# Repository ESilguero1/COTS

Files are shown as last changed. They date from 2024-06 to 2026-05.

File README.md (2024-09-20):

Celestial Object Tracking System is our take on GOTO teslescope systems with extra features
telescope







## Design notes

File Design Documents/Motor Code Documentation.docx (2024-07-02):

# MOTOR CODE DOCUMENTATION

Summer 2018

Jessica Chapman

Date | Editor | Reason
2018-08-29 | Jessica Chapman | Created Document

| Table of Contents
How it works | 1.1 Motor Setup | 1.1.1 Comm and Datagrams
| | 1.1.2 How to Use It
| | 1.1.3 Improvement
| | 1.1.4 Command Guide
Programming | 2.1 Motor Code | 2.1.1 How it Works
| | 2.1.2 Editing Code
Circuits | 3.1 Motor Circuit | 3.1.1 List of Supplies
| | 3.1.2 Pin Connection Guide
Appendix | 4.1 Additional Information | 4.1.1 List of Links

# 1.1 Motor Setup

## 1.1.1 Communication and Datagrams

The motor setup uses a TMC5130 board with a stepper motor and Arduino Mega. The TMC communicates with the Arduino using an SPI interface using a 40-bit datagram structure. The datagram is split into two parts: the address (8 bits) and the information to send (32 bits), with the MSB transmitting first, the MSB of the address (bit 39) will define whether it is going for read (0) or write (1) access. 0x80 can be added to the address to achieve write access instead of read access.

40 Bit SPI Datagram Structure Writing

7-Bit Address

38-32

32-Bit Data

31-0

40 Bit SPI Datagram Structure Reading

Previous 32-Bit Data

31-0

1

39

7-Bit SPI Status

38-32

0

39

The SPI has four main signal types going from the master (Arduino) to control the slave (TMC5130). To hook up multiple motor controllers, they can be daisy chained together and enabled for communication using the CSN Pin. Note that the clocks must be set properly so that the communication speed is within range for the master and the slaves.

SCK | Bus Clock Input
SDI | Serial Data Input
SDO | Serial Data Output
CSN | Chip Select Input (Active Low)

## 1.1.2 How to Use the Program to Control a Motor

The loop in the Motor Communication INO file should be as fast as possible so as not to clog up the serial monitor, which can cause NULL problems in a python file attempting to communicate to the Arduino. Currently the loop takes about 30-200 µsec to complete.

Process | Time [µsecond]
Feed in Serial Data | 20
User Control Via Joystick | 100
Seeking a Limit Switch | 12
Is moving to a Position | 50

To use it, open up the Arduino IDE and then open the serial monitor. Change the Baud Rate to 57600 and the motor initialization information should appear on the screen. You should hear a small humming sound coming from the motor. Type in the command using the ‘Input’ under ‘List of Commands’ below, you can also find them in the Enum.h file (type in the number not the name). Make sure every command ends in a “;” and there are no additional spaces. If you get an e,unknown command; it likely means you have not formatted it correctly. If the motor does not respond and you do not hear the humming, make sure you are supplying 24V to the motor.

1. Open up Arduino IDE and Serial Monitor
2. Set Baud Rate to 57600
3. Send a command in the format [number],[*args]; with no spaces, and a comma between each argument, with a semicolon at the end
4. An S,1; response means the command was properly received and processed and S,0; response means that the command was not properly received (check the amount of arguments or if you already have a process going on such as ‘Home’)

## 1.1.3 Suggestions for Improvement

- Better input command structure. There are safety features built in to send a failure status if the command is not correctly formatted or is missing an argument.
- Possibly building a GUI with python to call the different controls and such
- Hardware switch that overrides the current commands and goes straight to the Joystick control
- Checking motor is properly connected when sending commands (ie: code pings motor to see if it’s alive and then returns some sort of status bit or something)
- Output the position of the motor when using the joystick to find how far something is (maybe building an absolute and a relative position function)
- An easy set position on the joystick, click a button or something and the program sets the exact position of the motor as the home position
- An actual PCB / Enclosure, not just a messy breadboard. A box where you can just stick in an arduino cord to load code and the motor connections would be super nice

## 1.1.4 Command Guide

The setup uses a TMC5130 Board, Arduino Mega, Stepper Motor, and a Joystick. The code is based on a stepper motor with 256 microstep resolution. The motor is run off of 24V and the arduino can be controlled from the Arduino IDE Serial Monitor or a python script.

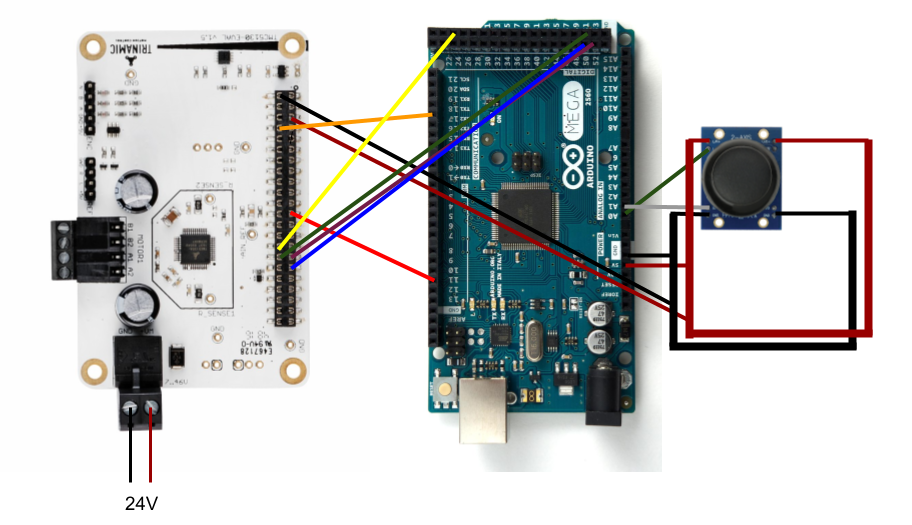
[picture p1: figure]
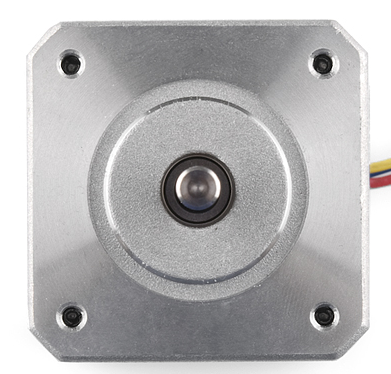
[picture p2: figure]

The setup also has the possibility for two limit switches to be added just above the motor connections, the switch configurations can be set using the commands below.

Default Settings of Motor Directions and Limit Switches
Forward Direction | Backward Direction | Right Limit Switch | Left Limit Switch
Clockwise | Counter-Clockwise | Forward Hit | Backward Hit

Note that the absolute position is described as the position relative to “Home” or point 0.

List of Commands
Command | Input | Output

Returns the 25-bit status from multiple registers. See table below for detailed description.
onRequestMotorStatus | 10; | m,[time],[bit0],[bit1],...,[bit24];

Returns the 10-bit status from the Drive Status Register. It gives a means to measure mechanical load on the motor, a value of 0 signals the highest load (stall).
onRequestStallStatus | 11; | g,[time],[bit0],[bit1],...,[bit9];

Changes the position specified to the current position of the motor (changes the step reference of the motor). The motor does not move to the specified position, but instead it becomes its position.
onRequestSetPosNoMove | 12; | d,[time],[oldPos],[newPos];

Gets the ADC bits from the Arduino (Mega = 10 bit ADC).
onGetADCBits | 20; | A,[ADC];

Gets the reference voltage of the Arduino (Mega = 5.0V)
onGetADCRefVolt | 21; | V,[5/3.3/2.56];

Gets the absolute position of the motor in microsteps.
onGetXactual | 22; | x,[time],[Xactual];

Gets the current velocity of the motor.
onGetVelocity | 23; | v,[time],[Velocity];

Gets the current maximum acceleration that the motor can achieve to reach maximum velocity.
onGetAcceleration) | 24; | a,[time],[Acceleration];

Gets the current maximum decceleration that the motor can achieve to reach 0 velocity.
onGetDeceleration | 25; | d,[time],[Decceleration];

Gets the IHOLD_IRUN (driver current control) power going to the motor
onGetPower | 26; | P,[time],[Power];

Moves the motor forward at the speed specified continuously until the motor is stopped or a limit switch is pressed. Note that forward defaults to clockwise.
onConstantForward | 30,[speed]; | S,[1/0];

Moves the motor backward at the speed specified continuously until the motor is stopped or a limit switch is pressed. Note that backward defaults to counterclockwise.
onConstantBackward | 31,[speed]; | S,[1/0];

Moves to the absolute position specified.
onMovePosition | 32,[absolute position]; | S,[1/0];

Moves a relative number of steps forward at the speed specified.
onMoveForward | 33,[number of steps],[speed]; | S,[1/0];

Moves a relative number of steps backward at the speed specified.
onMoveBackward | 34,[number of steps],[speed]; | S,[1/0];

Sets the maximum velocity achievable by the motor. For reference, the standard speed (ie: the speed of the motor used for onMovePosition) of the motor has been set to 100 000 µ/sec. 200 000 µ/sec is very fast, definitely do not exceed 300 000 µ/sec.
onVelocity | 35,[velocity]; | S,[1/0];

Sets the maximum acceleration achievable by the motor. The default is set to 50 000 µ/sec².
onAcceleration | 36,[acceleration]; | S,[1/0];

Sets the maximum decceleration achievable by the motor. The default is set to 50 000 µ/sec².
onDecceleration | 37,[decceleration]; | S,[1/0];

Sets the hold and run power going to the motor.
onPower | 38,[holdpower],[runpower]; | S,[1/0];

Sets the clockwise direction of the motor and the forward switch. See table below for detailed description.
onDirection | 39,[mode 1/2/3/4]; | S,[1/0];

Enable joystick control. A constant moving command will override the JS enable and disable the JS.
onJSEnable | 40; | S,[1/0];

Disable joystick control.
onJSDisable | 41; | S,[1/0];

Stop the motor. Can be used while any other command is currently going.
onMotorStop | 42; | S,[1/0];

Home the motor. The motor will run in the forward direction until it hits the forward limit switch and that will become the 0-point.
onMotorHome | 43; | S,[1/0];

Seek a limit switch in the direction specified.
onSeek | 44,[direction to go]; | S,[1/0];

Change the resolution of the motor, the possible settings are: 256, 128, 64, 32, 16, 8, 4, 2, 1. The motor defaults to 256.
onResolution | 45,[resolution]; | S,[1/0];

Set whether the switches are active high or active low. 0 = active high, 1 = active low.
onActiveSettings | 46, [fwActive],[bwActive]; | S,[1/0];

Request Motor Status
Bit Number | Status Bit
0 | status_sg2
1 | status_sg2_event
2 | status_standstill
3 | status_velocity_reached
4 | status_position_reached
5 | status_position_reached_event
6 | status_stop_l
7 | status_stop_r
8 | status_stop_l_event
9 | status_stop_r_event
10 | status_latch_l
11 | status_latch_r
12 | status_openLoad_A
13 | status_openLoad_B
14 | status_shortToGround_A
15 | status_shortToGround_B
16 | status_overtemperatureWarning
17 | status_overtemperatureShutdown
18 | status_isReverse
19 | status_resetDetected
20 | status_driverError
21 | status_underVoltage
22 | getIsForward
23 | getIsPositionMode
24 | getIsHomed

Setting Motor and Switch Directions
Direction Mode | Forward Switch | Backward Switch | Forward Direction | Backward Direction
1 | Right | Left | CW | CCW
2 | Right | Left | CCW | CW
3 | Left | Right | CW | CCW
4 | Left | Right | CCW | CW

# 2.1 Motor Code

## 2.1.1 How It Works

The code has a 3-level hierarchy, starting with the INO file at the top and hardware control files at the bottom. The Combined Control file controls the interactions between the joystick and the motor. Additional hardware classes should be incorporated into the Combined Control file. The code is currently only designed to control one motor, but motors could be daisy-chained together with some small edits to the code to control the slave enable-disable for multiple motors.

Combined Control

Motor INO

Joystick Control

Motor Control

### Motor Control File

At the lowest level, the motor is controlled by registers which you send values to through an SPI interface between the motor controller and the Arduino. The program uses datagram structures which are split into three parts: the read or write access (rw) which is bit 39, the address which is bits 38-32, and the data which is bits 31-0 (the datagrams are MSB first).

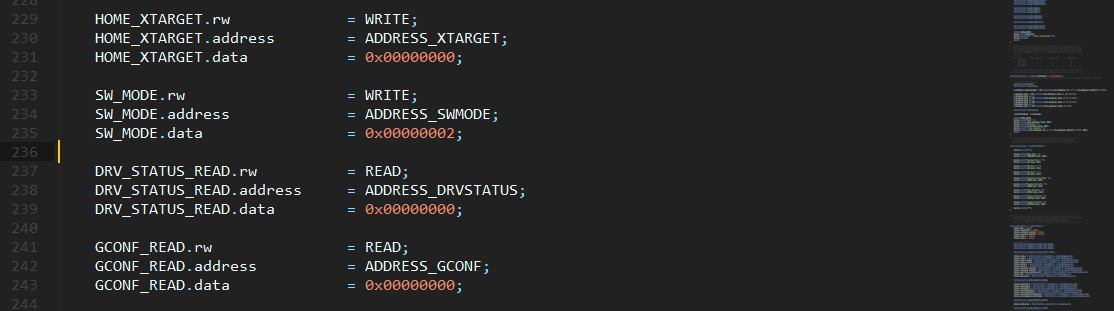
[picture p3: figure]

When reading from the motor controller, when you send a read command, the command after will be the one holding the information from the query, this can be seen in the MotorControl :: readStatus() function.

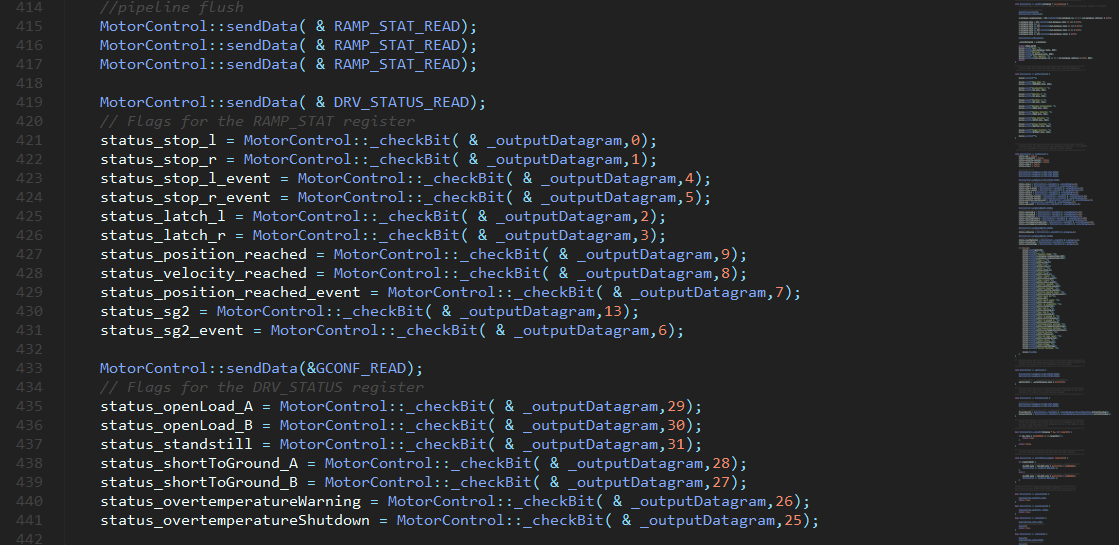
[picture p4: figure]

Note that the CS Pin for the motor controller that the command is meant for should only be enabled while sending the command and should be disabled after.

In addition, anything that requires movement, direction, or the limit switches should be done using the directionControl Struct. The forward/backward directions and limit switches are software controlled in Motor Control (instead of changing the registers, which causes many problems when ccw -/-> left switch and cw -/-> right switch).

### Joystick Control File

The joystick can be used to control many different aspects of the motor, such as speed, power, acceleration, direction. Currently it is set to control the speed and direction of motors. The Joystick control does not follow the settings for the forward and backward switches and motor directions.

Current Joystick Control Settings
Y-Direction | X-Direction
Speed of Motor | Direction of Motor

To save serial monitor time (sending bits to the register is a slow process), the Combined Control limits the values that will be updated such that the speed will only be updated if it is outside the range of +/-10% of the previous set reading.

## 2.1.2 Editing Code

To edit the code for more low level commands you need to use the registers provided in the definitions file and ensure the datagram has been set up (as that is how commands are sent to the motor). See chapter 6 (https://www.trinamic.com/fileadmin/assets/Products/ICs_Documents/TMC5130_datasheet_Rev1.15.pdf) for how to change the registers for what you need.

When you need to send information to the motor you should follow the format:

XTARGET.data = xtarget;

MotorControl :: sendData(&XTARGET);

To add new Serial Control Commands:

1. In the Enum.h file, add a definition ( __DEFINITION__ ) to the appropriate spot and assign a number
2. In MotorCommunication.ino under void attachCommandCallbacks() add your command using the format:

cmdMessenger.attach( __DEFINITION__, __FUNCTION__ );

3. Still in MotorCommunication.ino, add your function ( __FUNCTION__ )

To control the movement of the motor, I suggest calling one of the four already made functions (constForward, forward, constReverse, reverse) and using them in CombinedControl instead of making your own function in MotorControl; this is to keep from developing bugs in the software direction control. If you choose to make your own in MotorControl function, keep in mind the different ramp modes to use:

Ramp Mode | Position Mode | Direction
RAMP_MODE0 | True | --
RAMP_MODE1 | False | Forward
RAMP_MODE2 | False | Backward
RAMP_MODE3 | -- | --

# 3.1 Motor Circuit

## 3.1.1 List of Supplies

Supplies | Documentation | Additional Resources
TMC5130 Eval (https://www.trinamic.com/support/eval-kits/details/tmc5130-ev/) | User Manual and Cmd Guide (https://www.trinamic.com/fileadmin/assets/Products/Eval_Documents/TMC5130_Eval_manual.pdf) | Example Setup (http://blog.trinamic.com/2017/04/05/how-to-use-tmc5130-eval-with-your-arduino-mega/)
Arduino Mega 2560 (https://store.arduino.cc/usa/arduino-mega-2560-rev3) | Schematic (https://www.arduino.cc/en/uploads/Main/arduino-mega2560_R3-sch.pdf) | Pin Mapping (https://www.arduino.cc/en/Hacking/PinMapping2560)
2-Axis Joystick (https://www.parallax.com/product/27800) | Schematic (https://www.parallax.com/sites/default/files/downloads/27800-2-Axis-Joystick-Schematic-RevB.pdf) | Arduino Code (https://www.arduino.cc/en/Tutorial/JoyStick)

Additionally, the setup requires a stepper motor (https://catalog.orientalmotor.com/item/cvd-2-phase-bipolar-stepper-motor-drivers/legacy-pkp-series-2-phase-bipolar-stepper-motors/pkp244d23a), a 24V Power Cord + jack, 2 limit switches, a breadboard or PCB, and some jumper cables. Toggle switches are also useful for enabling/disabling the joystick and for turning on/off the power to the motor.

## 3.1.2 Pin Connection Guide

The pins going from the Arduino to the TMC5130 can be connected with or without the pin connector piece and Evaluation Platform (see page 5 (https://www.trinamic.com/fileadmin/assets/Products/Eval_Documents/TMC5130_Eval_manual.pdf)), the diagrams below do not use the pin connector.

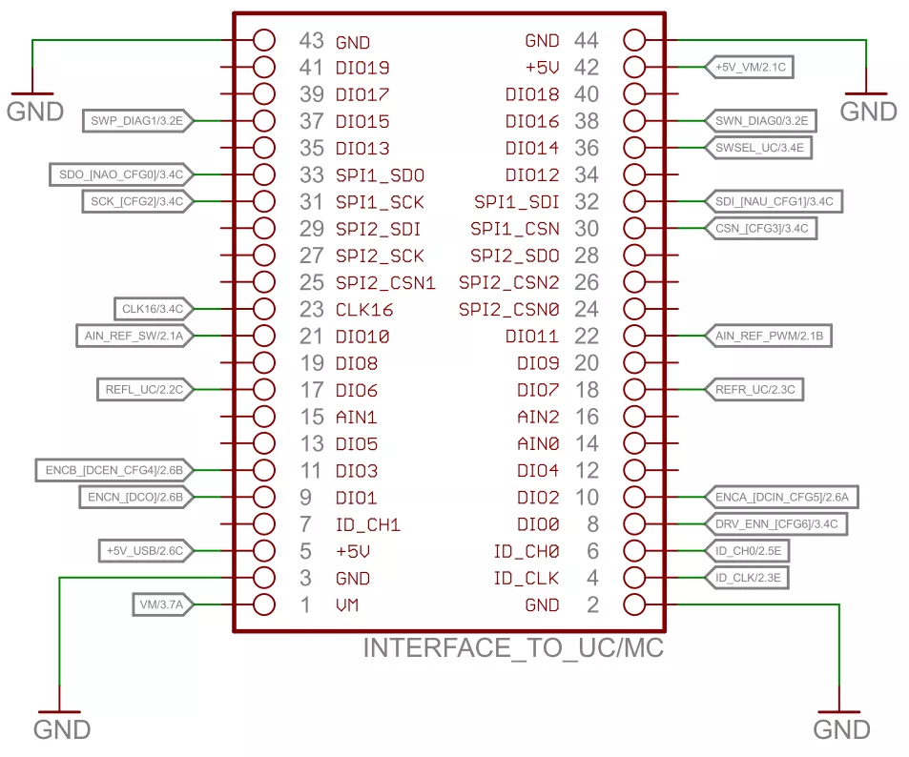
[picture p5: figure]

Arduino Pin | Type | TMC5130 Pin | Type | Colour
--- | GND | 2 | GND | Black
--- | 5V | 5 | +5V | Red
11 | DIO | 23 | CLK6 | Red
17 | DIO | 8 | DIO0 | Orange
25 | CS | 30 | SPI1_CSN | Yellow
50 | MISO | 33 | SPI1_SDO | Blue
51 | MOSI | 32 | SPI1_SDI | Purple
52 | SCK | 31 | SPI1_SCK | Green

Arduino Pin | Joystick | Colour
GND | Both GND Pins | Black
5V | L/R+ and U/D+ | Red
A0 | L/R | Green
A1 | U/D | Grey

# 4.1 Appendix

## 4.1.1 Relevant Links

GitHub | https://github.com/ProjektEskie/PNI-Sensors/tree/master/Motor%20Code
TMC5130 DataSheet | https://www.trinamic.com/fileadmin/assets/Products/Eval_Documents/TMC5130_Eval_manual.pdf
TMC5130 Cmd Guide | https://www.trinamic.com/fileadmin/assets/Products/ICs_Documents/TMC5130_datasheet_Rev1.15.pdf

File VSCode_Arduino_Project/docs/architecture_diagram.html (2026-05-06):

# COTS — Software Architecture

Arduino Due · TMC5130 × 3 · HWT906 IMU · BLE UART (Seeed nRF52) · Horizonless Embedded Solutions LLC

External Interfaces

Python Host

CmdMessenger protocol · USB Serial (COM3, 115200)

BLE Mobile App

Seeed nRF52 BLE UART · CRC32-framed packets

Application Layer

BLE_Bridge_App

Init · Service_BLE_UART()
println() → both channels

System_Control_App

ServiceSystemResponseApp() · 30+ CmdMessenger callbacks
Motor flags · seek/position state machine

HWT906_App

Init · CheckIMUDataCollection()
6-axis avg · UART1 interrupt

LED_App

Init state blink encoding
Service_LED() · Toggle_LED()

Scheduler · Main.cpp

loop()

SystemControlApp.Service()
BLE_App.Service_BLE_UART()
asyncTask.loop()

AsyncTask — Periodic Tasks

Mtr3PowerDisableCheck · 1000 ms ServiceIMUapp · 233 ms ServiceLEDapp · 250 ms ServiceJSswitch · 500 ms

setup()

Motor disable → LED → HWT906
→ SystemControl → BLE
→ Motor status checks

Middleware / Control Layer

CombinedControl

Wraps MotorControl[0..2] + Joystick
goPos · seek · constForward/Reverse · standstill · status()
Joystick enable/disable · range checks per motor

CmdMessenger

Serial command parser
feedinSerialData()
attach() callbacks

BLE Bridge Lib

build_frame_from_cstr()
parse_frame()
CRC32 (IEEE 802.3)

Driver Layer

MotorControl [0]

CS: pin 10 · ENA: pin 5
readStatus() · sendData()
RAMP_STAT.vzero · VACTUAL

MotorControl [1]

CS: pin 11 · ENA: pin 6
readStatus() · sendData()
RAMP_STAT.vzero · VACTUAL

MotorControl [2]

CS: pin 2 · ENA: pin 3
Low-vel vertical axis
Auto power-disable

Joystick

A0 (Y) · A1 (X)
xAxisControl() · yAxisControl()
Threshold + range scaling

Hardware Abstraction (Arduino Framework)

SPI (MODE3 · MSBFIRST · DIV8)

40-bit pipelined datagrams · CS per motor · 1-transaction read delay

UART1 (Serial1)

HWT906 IMU
pins 18/19

UART3 (Serial3)

BLE UART
pins 16/17

ADC · GPIO

A0/A1 joystick
pin 12 LED · pin 13 JS-SW

Hardware

TMC5130 #0

Stepper Motor 0
Azimuth / Yaw axis
±180° range-limited

TMC5130 #1

Stepper Motor 1
Elevation / Pitch axis
±90° range-limited

TMC5130 #2

Stepper Motor 2
Vertical / Lift axis
On-demand power

HWT906 IMU

6-axis AHRS
Accel · Gyro · Mag
Heading + attitude

BLE Module

Seeed nRF52
BLE UART peripheral

Arduino Due

SAM3X8E
ARM Cortex-M3 · 84 MHz

External Interface

Application

Scheduler / Main

Middleware

Driver

HAL

Hardware

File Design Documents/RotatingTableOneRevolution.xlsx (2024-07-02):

Microsteps (Controller Setting) | Motor (1.8) 360/1.8 | 1 motor revolution (uSteps*1.8) | Transmission mode: worm gear (reduction ratio 1/180) | 1 Rotating Table revolution | Steps to move 1 degree
256 | 200 | 51200 | 180 | 9216000 | 25600

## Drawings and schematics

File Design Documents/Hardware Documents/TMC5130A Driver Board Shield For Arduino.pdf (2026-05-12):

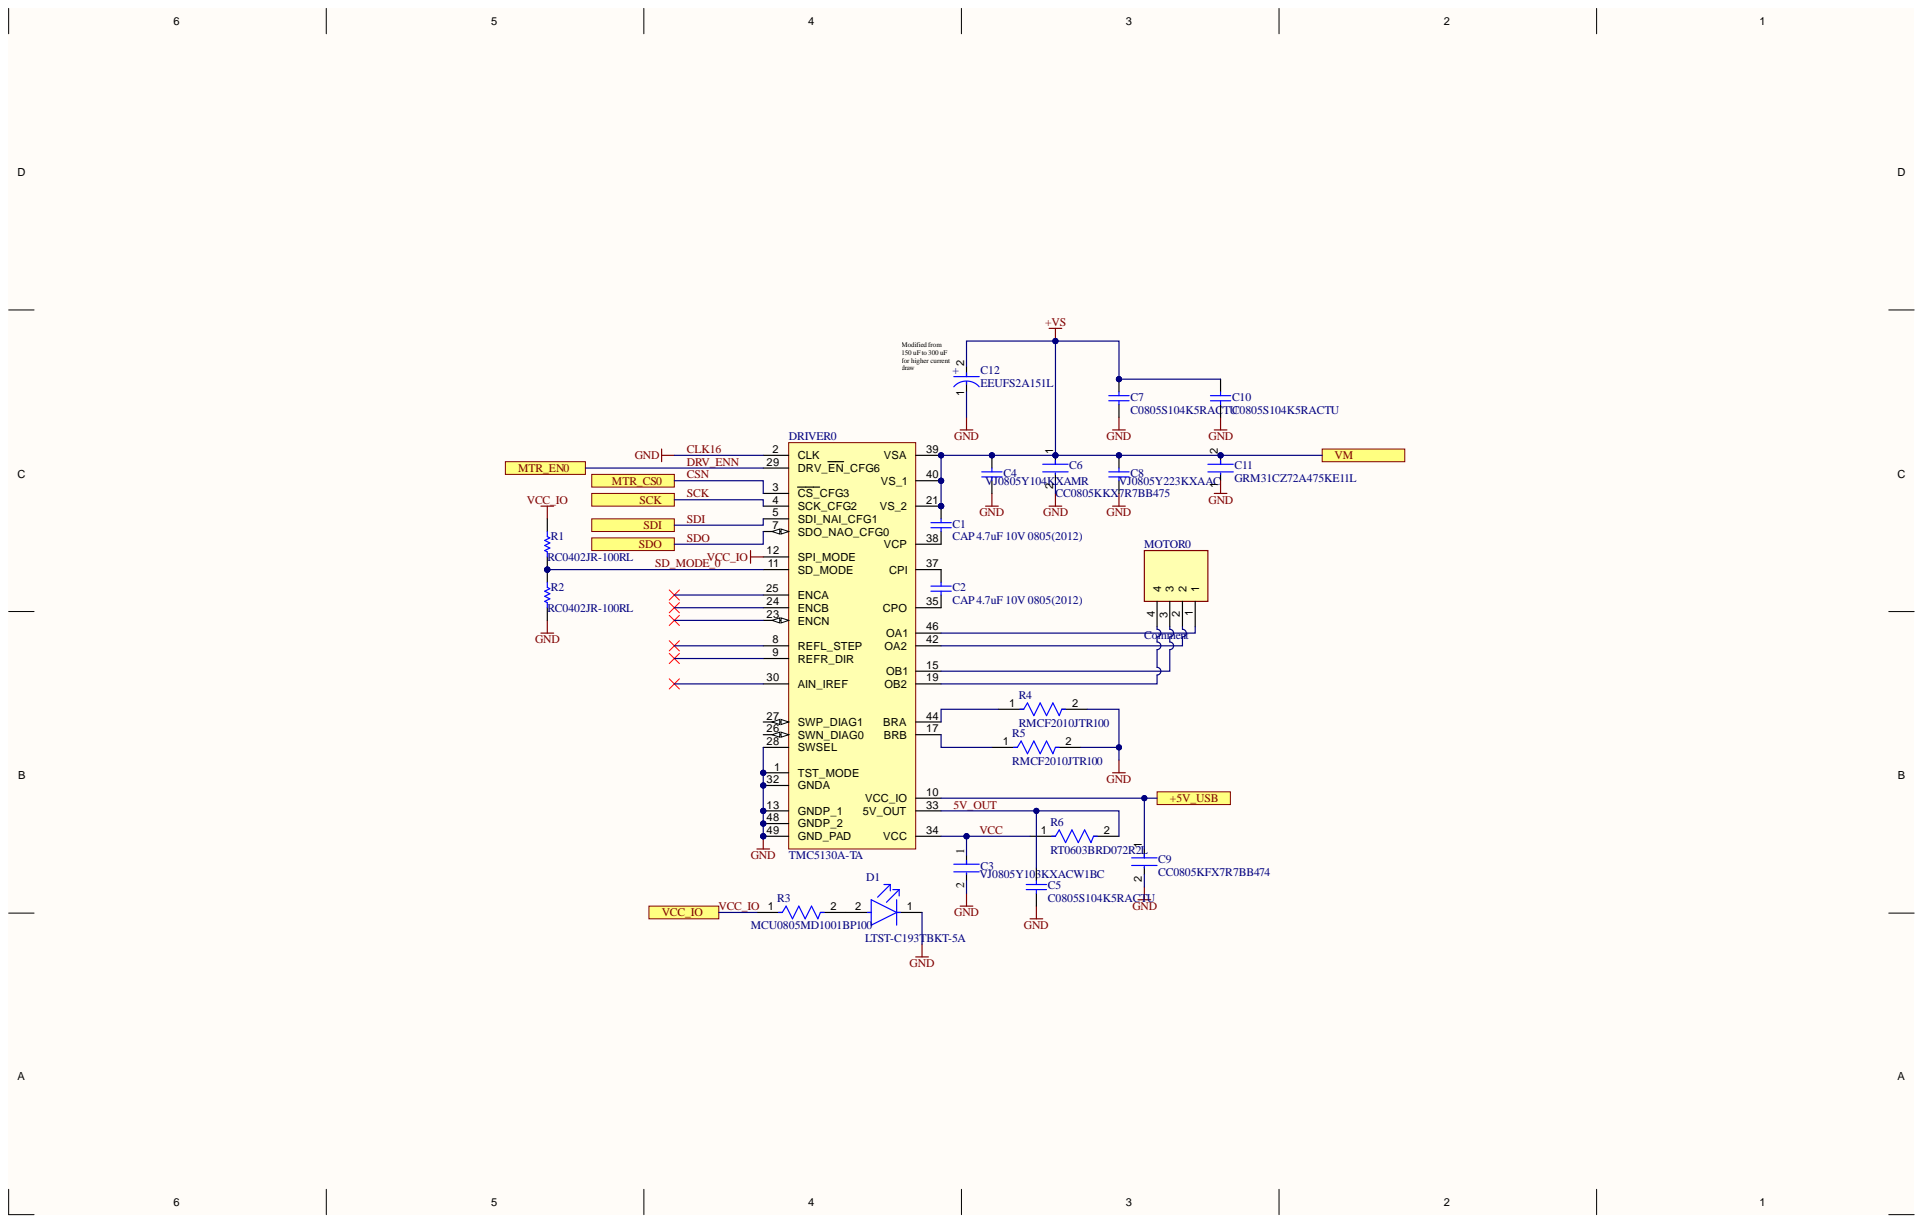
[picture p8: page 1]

SCK | SCK | SCK_CFG2 4

SDI | | SDO_NAO_CFG0 7
SDO | SDO | | SD_MODE 11 SPI_MODE 12

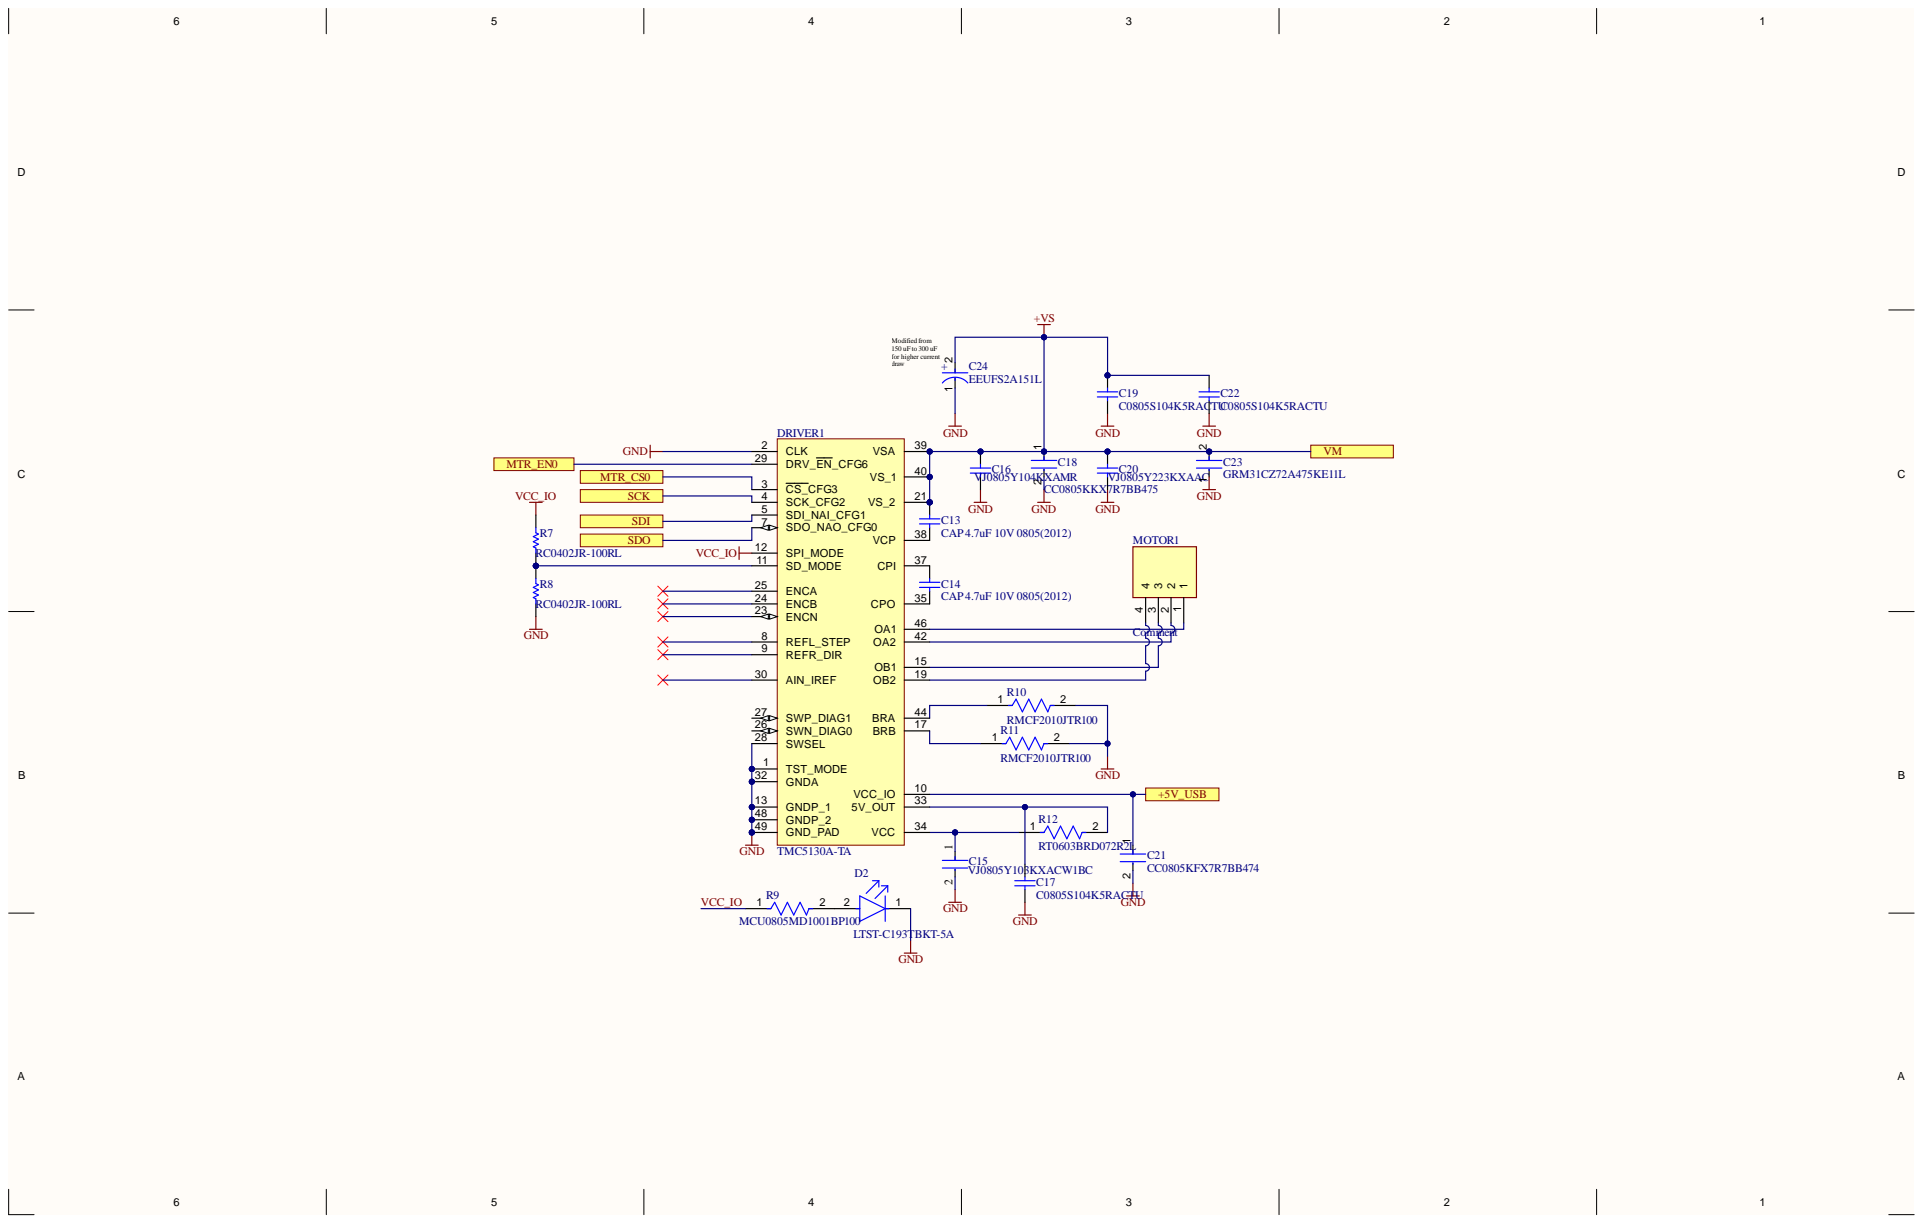
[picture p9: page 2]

MTR_EN0 | CS_CFG3 3

SDI | SDO_NAO_CFG0 7

SD_MODE 11 SPI_MODE 12

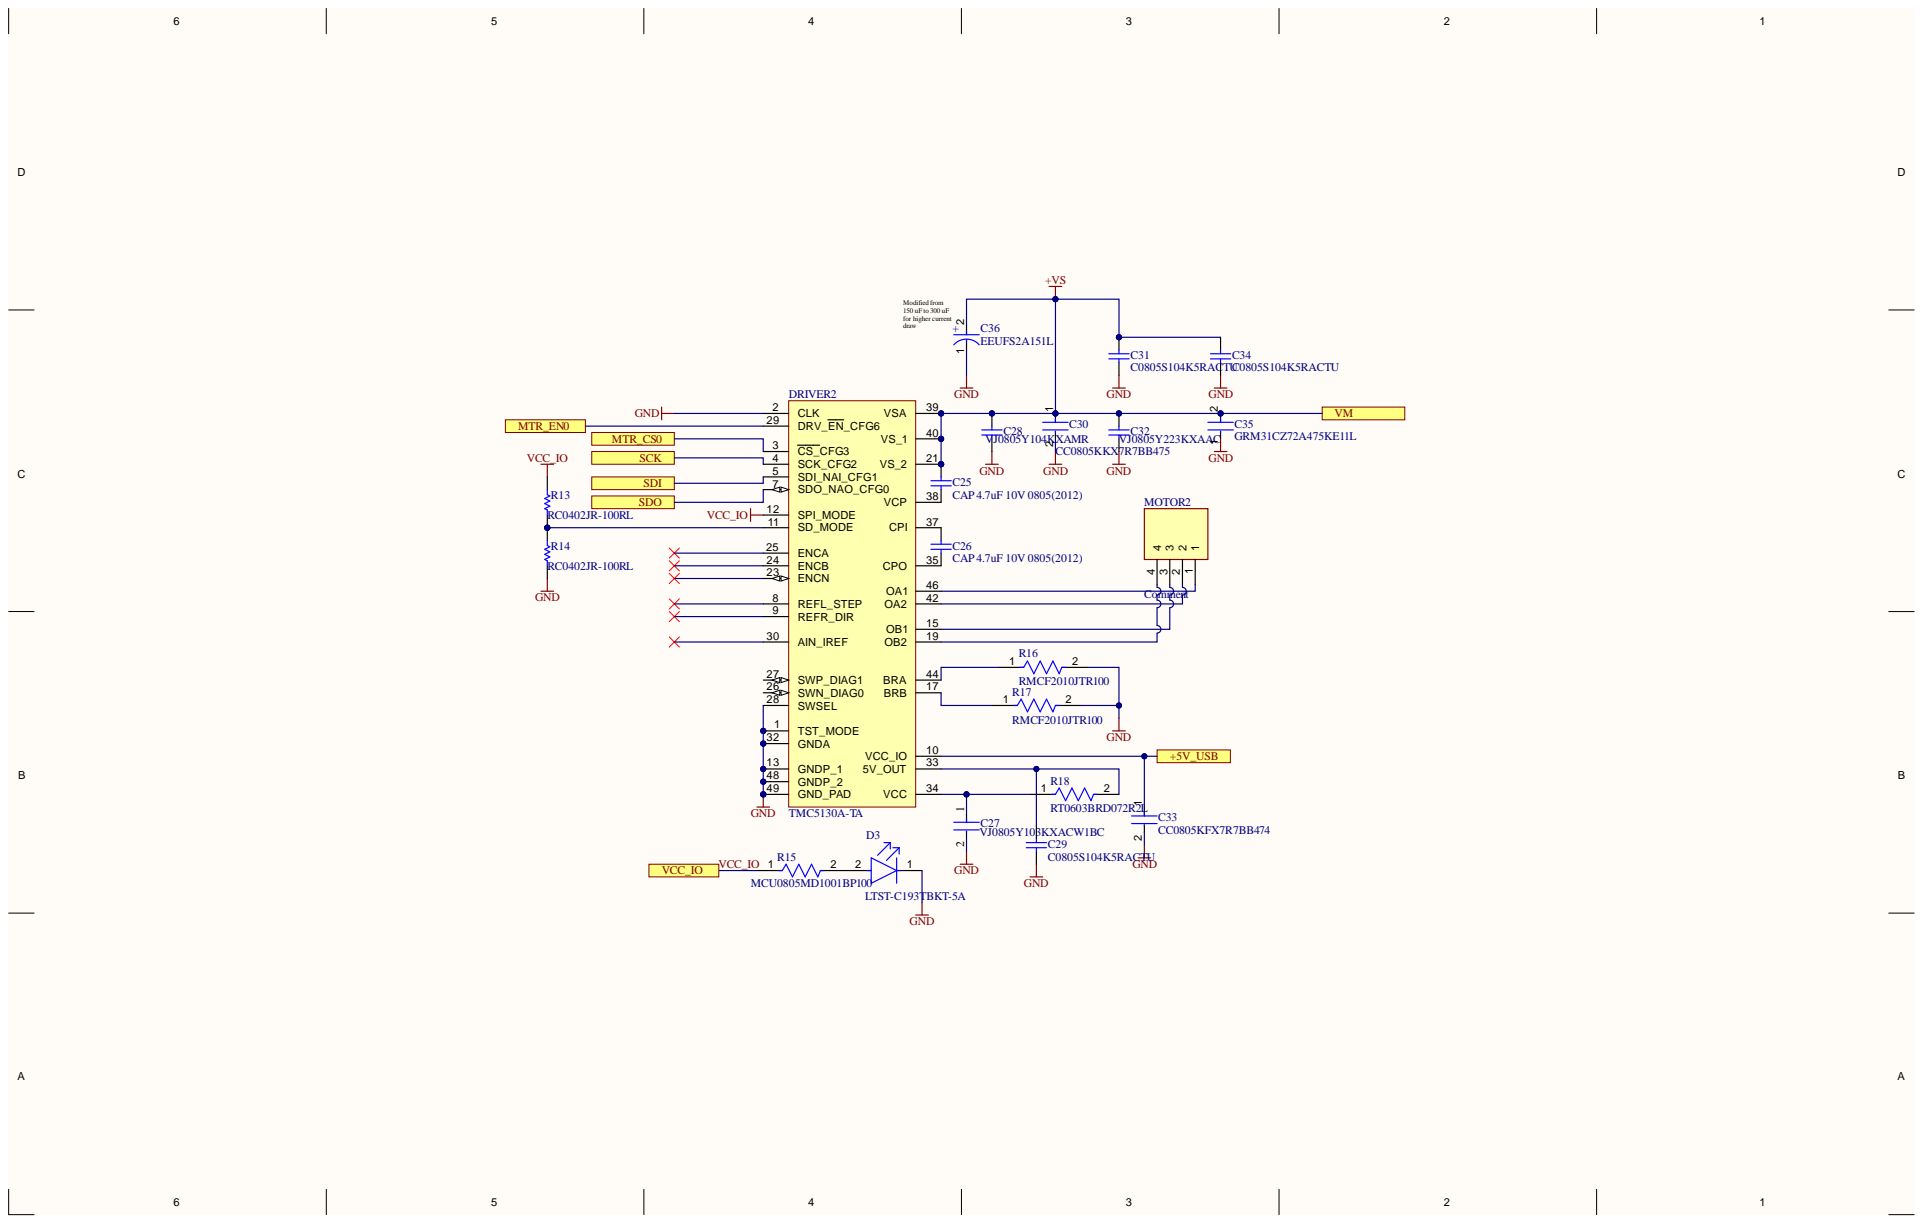
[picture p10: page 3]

MTR_CS0 | CS_CFG3 3
SCK | SCK_CFG2 4

SDI | SDO_NAO_CFG0 7
SDO | SD_MODE 11 SPI_MODE 12

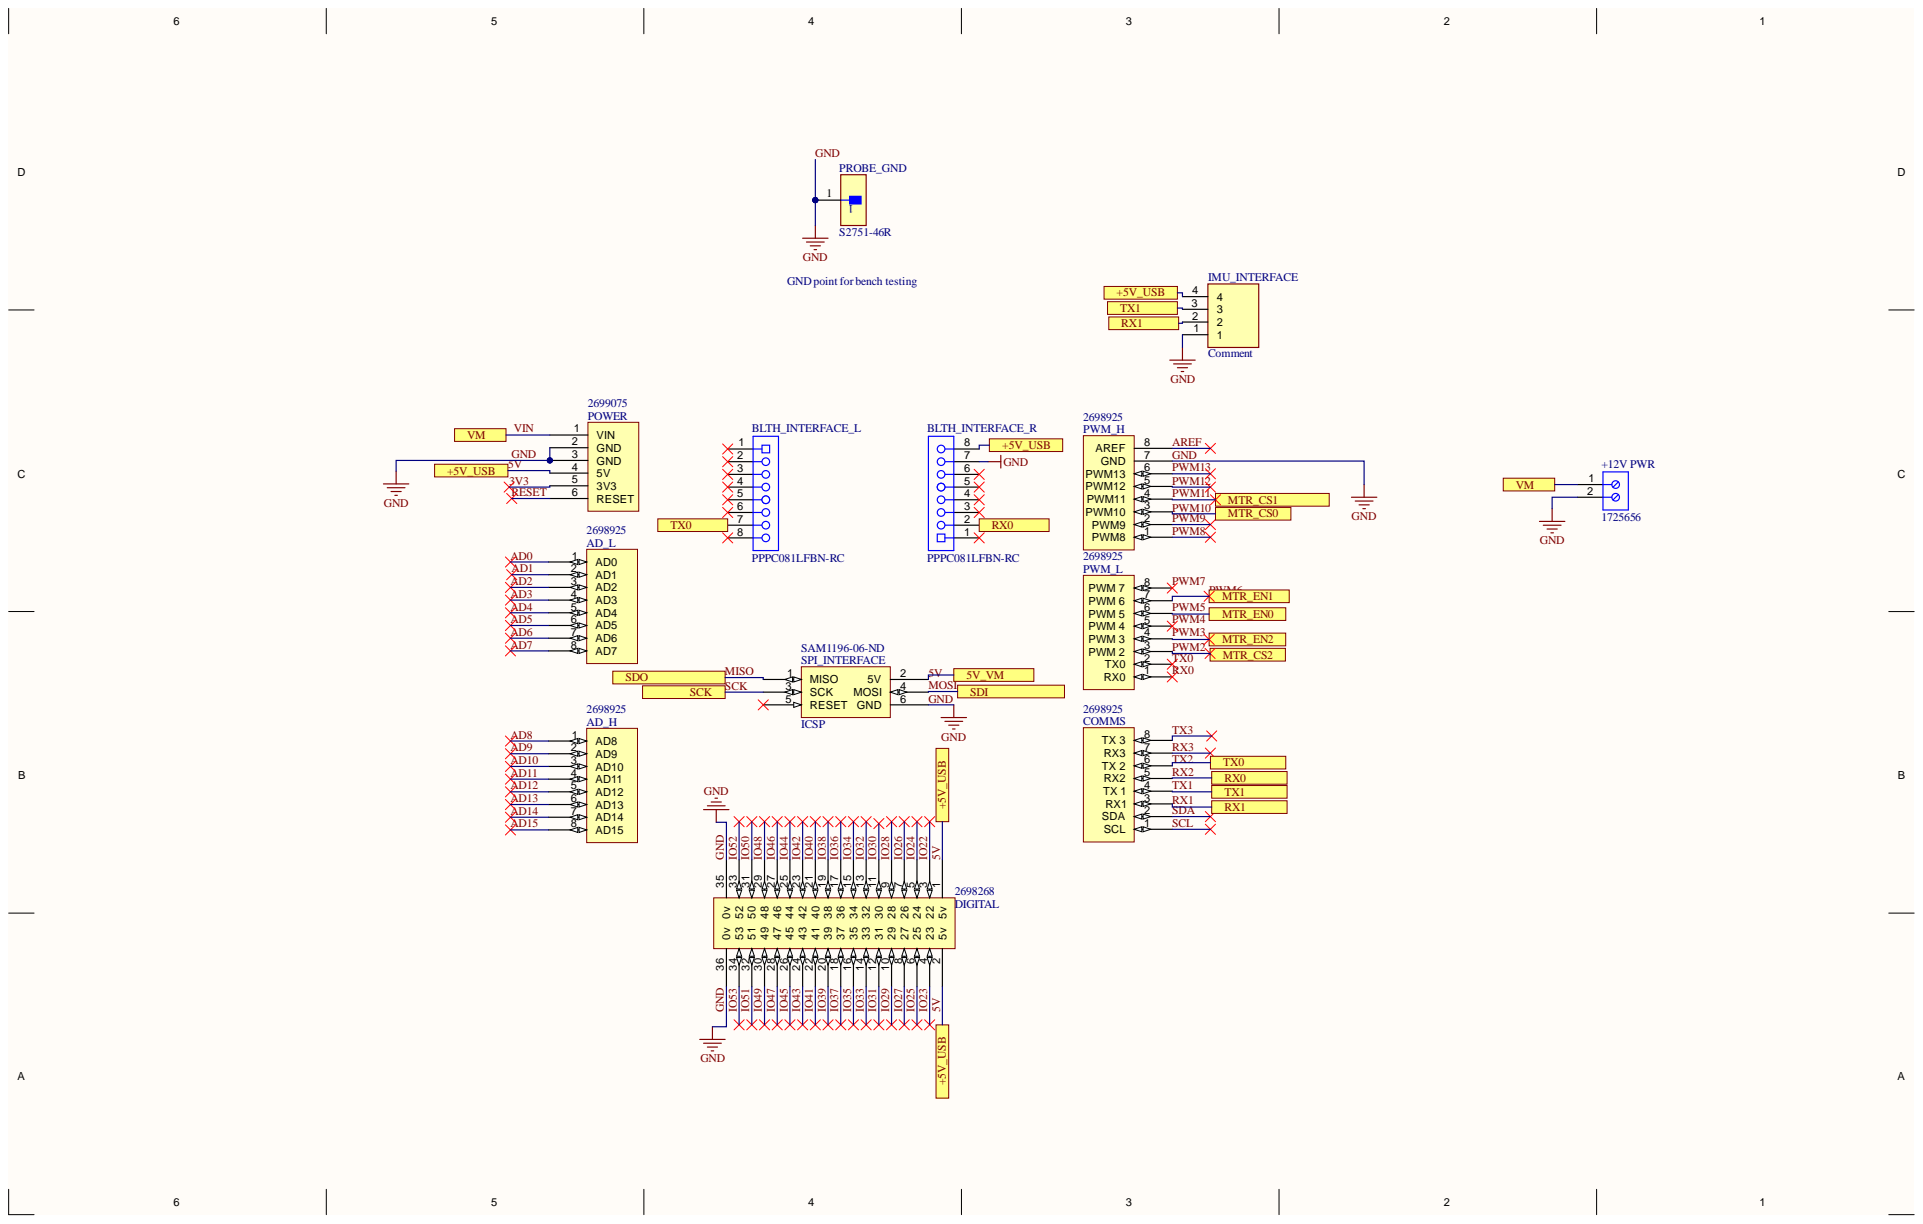
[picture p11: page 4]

SCK | SDI | COMMS

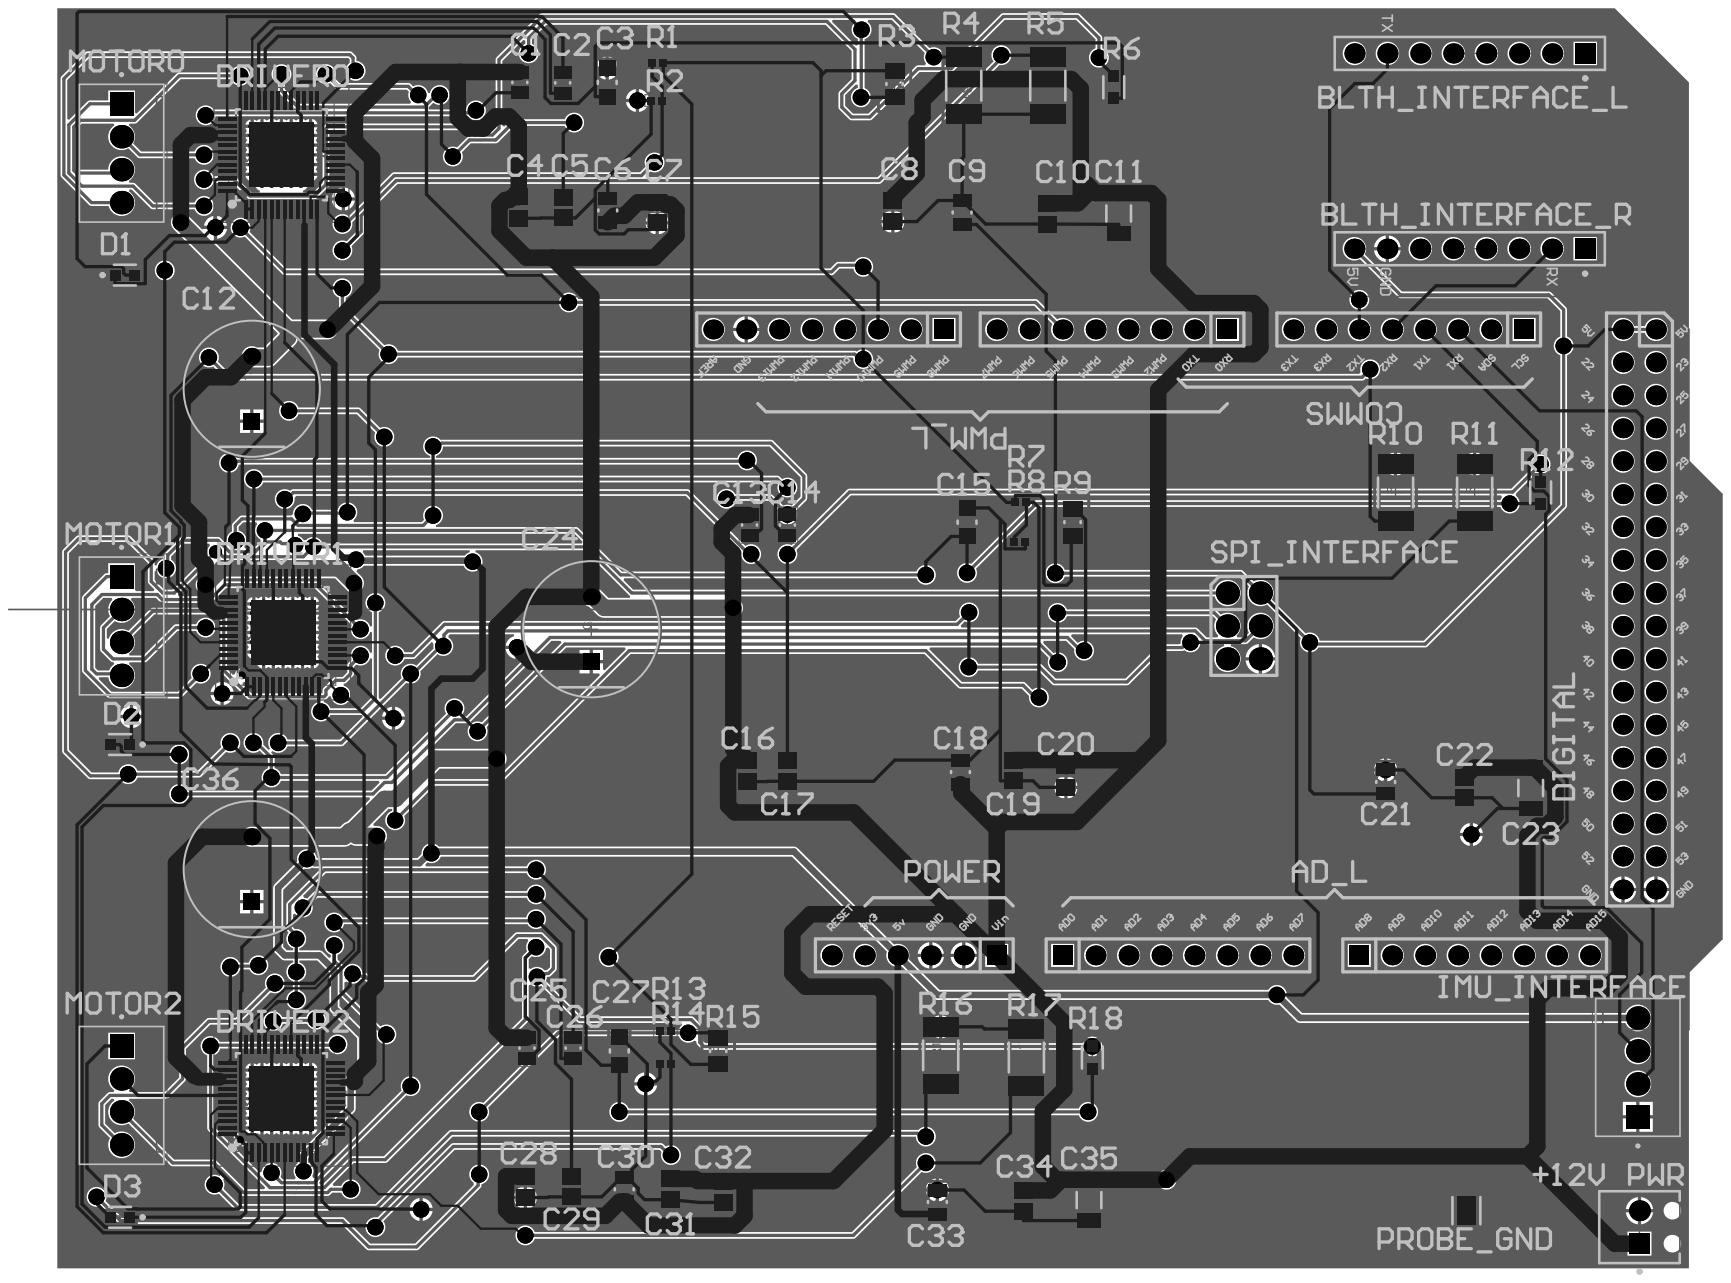
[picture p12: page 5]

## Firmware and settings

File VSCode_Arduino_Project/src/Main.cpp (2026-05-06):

/***********************************************************************************************//**
 * @file       Main.cpp
 * @details    Main COTS application. Schedule system services tasks
 * @author      Miguel Silguero
 * @copyright  Copyright (c) 2024-2025, Horizonless Embedded Solutions LLC
 * @date       08.06.2024 (created)
 *
 **************************************************************************************************/

/***************************************************************************************************
 * INCLUDES
 **************************************************************************************************/
#include "System_definitions.h"
#include "debugutils.h"
#include "CombinedControl.h"
#include "BLE_Bridge_App.h"
#include "System_Control_App.h"
#include "HWT906_App.h"
#include "LED_App.h"
#include <AsyncTask.h>

/***************************************************************************************************
 * CONSTANTS AND DEFINITIONS
 **************************************************************************************************/

/***************************************************************************************************
 * MODULE VARIABLES
 **************************************************************************************************/
AsyncTask asyncTask;                 /* Handles asynchronous tasks */
HWT906_App HWT906App;                /* IMU application object */
BLE_Bridge_App BLE_App;            /* Bluetooth application object */
System_Control_App SystemControlApp; /* System control application object */
LED_App LEDApp;                      /* IMU application object */
uint8_t SystemInitState = 0; /* Tracks initialization status of the system */

/***************************************************************************************************
 * PRIVATE FUNCTION PROTOTYPES
 **************************************************************************************************/
void Mtr3PowerDisableCheck(void);   /* Checks if motor 3 should be powered down */
void ServiceIMUapp(void);           /* Handles periodic IMU data servicing */
void ServiceLEDapp(void);           /* Handles periodic LED service */
void ServiceJSswitch(void);

/***********************************************************************************************//**
 * @details     Setup for main program. Initialize all subsystems and report any failures
 **************************************************************************************************/
void setup()
{
    /* disable all motors */
    pinMode(MTR_ENA_0, OUTPUT);
    pinMode(MTR_ENA_1, OUTPUT);
    pinMode(MTR_ENA_2, OUTPUT);
    digitalWrite(MTR_ENA_2, HIGH);
    digitalWrite(MTR_ENA_0, HIGH);
    digitalWrite(MTR_ENA_1, HIGH);
    delay(200);
    LEDApp.Init();

    if (HWT906App.Init() != 0)              /* Initialize HWT906 IMU module */
    {
         SystemInitState |= (1 << INIT_HWT906_STAT_FAILED);
 }

    SystemControlApp.Init();                /* Initialize system control */

    if (BLE_App.Init() != 0) /* Initialize Bluetooth Low Energy (BLE) module */
    {
       SystemInitState |= (1 << INIT_BLE_STAT_FAILED);
    }

    /* Check motor initialization status and set failure flags if needed */
    if ((SystemControlApp.RequestMotorStatus(0) < MOTOR_OK_STATUS[0]) || (SystemControlApp.RequestMotorStatus(0) > MOTOR_OK_STATUS_1[0]))
    {
        SystemInitState |= (1 << INIT_MOTOR1_STAT_FAILED);
    }
    if ((SystemControlApp.RequestMotorStatus(1) < MOTOR_OK_STATUS[1]) || (SystemControlApp.RequestMotorStatus(1) > MOTOR_OK_STATUS_1[1]))
    {
        SystemInitState |= (1 << INIT_MOTOR2_STAT_FAILED);
    }
    if ((SystemControlApp.RequestMotorStatus(2) < MOTOR_OK_STATUS[2]) || (SystemControlApp.RequestMotorStatus(2) > MOTOR_OK_STATUS_1[2]))
    {
        SystemInitState |= (1 << INIT_MOTOR3_STAT_FAILED);
    }



    /* enable all, but motor 3 on startup */
    digitalWrite(MTR_ENA_0, LOW);
    digitalWrite(MTR_ENA_1, LOW);
    digitalWrite(MTR_ENA_2, HIGH);

    SystemControlApp.SetSysInitstate(SystemInitState);               /* Prep Report intialization state*/
    LEDApp.Set_LED_Code(SystemInitState);                           /* Enunciate system intialization state*/

    /* Schedule periodic tasks for motor power check and IMU servicing */
    asyncTask.repeat(Mtr3PowerDisableCheck, 1000);                  /* Check motor power every second */
    asyncTask.repeat(ServiceIMUapp, IMU_DATA_ACQUSITION_PERIOD);    /* Service IMU periodically */
    asyncTask.repeat(ServiceLEDapp, LED_FREQ_RATE_MS);              /* Service LED periodically */
    asyncTask.repeat(ServiceJSswitch, JS_SWITCH_CHK);              /* Service JS swtich periodically */
}

/***********************************************************************************************//**
 * @details     Main loop
 **************************************************************************************************/
void loop()
{
    SystemControlApp.ServiceSystemResponseApp();        /* Process system responses */
    BLE_App.Service_BLE_UART();                         /* Handle BLE communication */
    asyncTask.loop();                                   /* Execute other async scheduled tasks */
}

/***********************************************************************************************//**
 * @details     After motor 3 is enabled, this function checks if velocity is below
 a value before shutting the motor down.
 **************************************************************************************************/
void Mtr3PowerDisableCheck(void) 
{
	SystemControlApp.ServiceMotor3PowerDisable();
}

/***********************************************************************************************//**
 * @details     HWT906 data is collected using an interrupt, this checks for new data and sets errors
 **************************************************************************************************/
void ServiceIMUapp(void)
{
    if ((SystemInitState & (1 << INIT_HWT906_STAT_FAILED)) == 0 ) /*ONly run if init passed for device*/
    {
        HWT906App.CheckIMUDataCollection();	
    }
}

/***********************************************************************************************//**
 * @details     Service LED application every LED_FREQ_RATE_HZ ms
 **************************************************************************************************/
void ServiceLEDapp(void)
{
    LEDApp.Service_LED();
}

/***********************************************************************************************//**
 * @details     Service Joystick mode switch debouncing every JS_SWITCH_CHK ms
 *  The the jostick mode determines if the joystick controls motor 3 only or ignores motor 3
 * and services motors 1 & 2
 **************************************************************************************************/
void ServiceJSswitch(void)
{
    // static int lastJSstate = HIGH;
    // int JSstate = PIOB->PIO_PDSR & PIO_PDSR_P27;

    // if ((lastJSstate == LOW) & (JSstate = LOW))
    // {
    //     //SystemControlApp.ToggleJSmtrlControlMode();
    // }
    // lastJSstate = JSstate;

    //SystemControlApp.SendIMUdataFrame();
}

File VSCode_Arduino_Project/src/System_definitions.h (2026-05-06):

/***********************************************************************************************//**
 * @file       System_definitions.h
 * @details
 * @author      Miguel Silguero
 * @copyright  Copyright (c) 2024-2025, Horizonless Embedded Solutions LLC
 * @date       11.13.2024 (created)
 *
 **************************************************************************************************/
#ifndef SYSTEM_DEFINITIONS_H
#define SYSTEM_DEFINITIONS_H

/***************************************************************************************************
 * CONSTANTS AND DEFINITIONS
 **************************************************************************************************/

 //#define I2C_SDA             (20) 
 //#define I2C_SCL             (21)

 //#define BLUEFRUIT_SPI_RST   (16)
 #define JS_STOP_SWTICH      (13)
 #define SYS_LED             (12)
 #define MTR_CS1             (11) 
 #define MTR_CS0             (10)    
 #define BLUEFRUIT_SPI_CS    (8)
 #define BLUEFRUIT_SPI_IRQ   (7)
 #define MTR_ENA_1           (6)
 #define MTR_ENA_0           (5)
 //#define BLUEFRUIT_INTERRUPT (4)
 #define MTR_ENA_2           (3)
 #define MTR_CS2             (2) 
 /* UART RX and TX pins 0 and 1 are reserved*/
 

#define PIN_TX3 16  /*BLE interface*/
#define PIN_RX3 17  /*BLE interface*/
#define PIN_TX1 18  /*HWT906 interface*/
#define PIN_RX1 19  /*HWT906 interface*/



 #define JS_XAXIS_INPUT A1
 #define JS_YAXIS_INPUT A0
 #define ADC_RESOLUTION_FLOAT 1024.0
 
 // Debug Options (set to #ifdef)
 //#define DEBUG_MOTOR  0
 // #define DEBUG_HOME 0
 //#define DEBUG_DIR   1
// #define DEBUG_COM

// Debug options
//#define MOTOR_DEBUG 1

 // Additional constants
 #define STAND_MTR_VELOCITY 	  (45000)
 #define STAND_MTR3_VELOCITY    (250)
 #define MTR3_HOLD_POWER        (1)
 #define MTR3_RUN_POWER         (20)
 #define MTR3_ACCELERATION      (20)

 #define MTR_STATUS_SIZE	      (25)
 #define MOTOR_MICRO_STEPS      (200) //Motor is (1.8) 360/1.8
 #define MOTOR_STEPS_PER_DEGREE (25600)

/***************************************************************************************************
 * TYPEDEFS
 **************************************************************************************************/
union floatUnion
{
  int i;
  float f;
}; /* This union to used to convert between the binary representations of integers and floats */

typedef enum 
{
    // Init State machine definitions
    INIT_BLE_STAT_FAILED      = 0,
    INIT_HWT906_STAT_FAILED      = 1,
    INIT_MOTOR1_STAT_FAILED      = 2,
    INIT_MOTOR2_STAT_FAILED      = 3,
    INIT_MOTOR3_STAT_FAILED      = 4,
} SystemInitState_e;


const unsigned long MOTOR_OK_STATUS[3] = {12500000, 12500000, 12500000};

const unsigned long MOTOR_OK_STATUS_1[3] = {13200000, 13200000, 13200000};



#endif

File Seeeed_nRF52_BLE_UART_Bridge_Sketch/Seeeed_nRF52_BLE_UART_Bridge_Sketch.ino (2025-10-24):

// XIAO nRF52840 BLE <-> Serial1 bridge with framing and CRC32
//
// Role:
// 1. BLE -> Serial1: Buffers data received from BLE until ';' is seen, then
//    sends the accumulated payload in a framed packet over Serial1.
// 2. Serial1 -> BLE: Parses framed packets [0x55 0xAA][len(2 BE)][payload][crc32(4 LE)].
//    If the CRC is valid, the payload is forwarded to the BLE UART.
//
// Robustness:
// - CRC32 is used for data integrity check (glitch detection).
// - Frame parsing includes a resynchronization mechanism (discarding bytes until markers are found).
// - Length sanity checks are enforced to prevent buffer overflow from corrupted headers.

#include <bluefruit.h>
#include <Arduino.h>

// --- Configuration ---
// Secondary UART settings
#define SERIAL1_BAUD 115200

// Define SERIAL_DEBUG 1 to enable Serial output for debugging
//#define SERIAL_DEBUG 1

// Framing constants
const uint8_t FRAME_MARKER_H = 0x55;
const uint8_t FRAME_MARKER_L = 0xAA;
const size_t CRC_SIZE = 4;
const size_t HEADER_SIZE = 2 + 2; // Marker (2) + Length (2)
const size_t FRAME_OVERHEAD = HEADER_SIZE + CRC_SIZE;

// --- Buffers and State ---
// Serial1 RX Buffer (Max frame size supported)
const size_t SERIAL1_RX_BUF = 512;
uint8_t serial1_buf[SERIAL1_RX_BUF];
size_t serial1_buf_len = 0;
const uint16_t MAX_PAYLOAD_LEN = SERIAL1_RX_BUF - FRAME_OVERHEAD;

// BLE RX buffering until semicolon (packet delimiter)
const size_t BLE_ACCUM_BUF = 512;
uint8_t ble_accum[BLE_ACCUM_BUF];
size_t ble_accum_len = 0;

// BLE UART Service
BLEUart bleuart;

// --- CRC32 Implementation ---
uint32_t crc_table[256];

void crc32_init() {
    const uint32_t poly = 0xEDB88320UL;
    for (uint32_t i = 0; i < 256; ++i) {
        uint32_t c = i;
        for (uint32_t j = 0; j < 8; ++j) {
            if (c & 1) c = poly ^ (c >> 1);
            else c >>= 1;
        }
        crc_table[i] = c;
    }
}

uint32_t crc32_compute(const uint8_t *data, size_t len) {
    uint32_t c = 0xFFFFFFFFUL;
    for (size_t i = 0; i < len; ++i) {
        uint8_t idx = (uint8_t)((c ^ data[i]) & 0xFF);
        c = crc_table[idx] ^ (c >> 8);
    }
    return c ^ 0xFFFFFFFFUL;
}

// --- Helper Functions for Endianness ---

// Write unsigned 16-bit integer as Big Endian
void write_u16_be(uint8_t *dst, uint16_t v) {
    dst[0] = (v >> 8) & 0xFF;
    dst[1] = v & 0xFF;
}

// Write unsigned 32-bit integer as Little Endian
void write_u32_le(uint8_t *dst, uint32_t v) {
    dst[0] = v & 0xFF;
    dst[1] = (v >> 8) & 0xFF;
    dst[2] = (v >> 16) & 0xFF;
    dst[3] = (v >> 24) & 0xFF;
}

// Read unsigned 16-bit integer as Big Endian
uint16_t read_u16_be(const uint8_t *src) {
    return (uint16_t(src[0]) << 8) | uint16_t(src[1]);
}

// Read unsigned 32-bit integer as Little Endian
uint32_t read_u32_le(const uint8_t *src) {
    return uint32_t(src[0]) | (uint32_t(src[1]) << 8) | (uint32_t(src[2]) << 16) | (uint32_t(src[3]) << 24);
}

// --- Communications Functions ---

// Build and send frame containing payload to Serial1
void send_frame_to_serial1(const uint8_t *payload, uint16_t payload_len) {
    // Safety check: ensure the frame fits in the buffer
    if ((size_t)payload_len > MAX_PAYLOAD_LEN) {
        #ifdef SERIAL_DEBUG
        Serial.print("ERROR: BLE payload too large (");
        Serial.print(payload_len);
        Serial.println(" bytes). Dropped.");
        #endif
        return;
    }

    // This buffer is large enough as checked by MAX_PAYLOAD_LEN
    uint8_t frame[SERIAL1_RX_BUF];
    size_t idx = 0;

    // 1. Frame Markers
    frame[idx++] = FRAME_MARKER_H;
    frame[idx++] = FRAME_MARKER_L;
    
    // 2. Payload Length (Big Endian)
    write_u16_be(frame + idx, payload_len); 
    idx += 2;
    
    // 3. Payload Data
    memcpy(frame + idx, payload, payload_len); 
    idx += payload_len;
    
    // 4. CRC32 Checksum (Little Endian)
    uint32_t crc = crc32_compute(payload, payload_len);
    write_u32_le(frame + idx, crc); 
    idx += 4;

    // Send the complete frame
    Serial1.write(frame, idx);
    Serial1.flush();
}

// BLE RX callback: accumulate until semicolon found, then send framed packet to Serial1
void ble_rx_callback(uint16_t conn_hdl) {
    const size_t CHUNK = 128; // Use local const for read chunk size
    uint8_t buf[CHUNK];

    // Read in a loop until no more data
    while (true) {
        int n = bleuart.read(buf, CHUNK);
        if (n <= 0) break;

        // Process n bytes, accumulating until a ';' packet delimiter is found
        for (int i = 0; i < n; ++i) {
            uint8_t received_byte = buf[i];
            
            // Sliding window buffer management: append new byte, dropping oldest if full
            if (ble_accum_len < BLE_ACCUM_BUF) {
                ble_accum[ble_accum_len++] = received_byte;
            } else {
                // Drop the oldest byte (at index 0) to make room for the new one
                memmove(ble_accum, ble_accum + 1, BLE_ACCUM_BUF - 1);
                ble_accum[BLE_ACCUM_BUF - 1] = received_byte;
                // ble_accum_len remains BLE_ACCUM_BUF
            }

            if (received_byte == ';') {
                // Find the first semicolon in the accumulated buffer
                size_t pos = 0;
                while (pos < ble_accum_len && ble_accum[pos] != ';') pos++;

                if (pos < ble_accum_len) {
                    // A complete command is found (including the ';')
                    size_t payload_len = pos + 1;

                    // Send the command as a framed packet over Serial1
                    send_frame_to_serial1(ble_accum, (uint16_t)payload_len);

                    // Consume the transmitted command and shift remaining data
                    size_t remaining = ble_accum_len - payload_len;
                    if (remaining) {
                        memmove(ble_accum, ble_accum + payload_len, remaining);
                    }
                    ble_accum_len = remaining;
                }
            }
        }
    }
}
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

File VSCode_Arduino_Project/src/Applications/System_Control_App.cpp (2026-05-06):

/***********************************************************************************************//**
 * @file       BNO080_App.cpp
 * @details    System control application module. Motors and joystick initialization.
 *             Services serial communication requests and responses.
 * @author		Miguel Silguero
 * @copyright  Copyright (c) 2024-2025, Horizonless Embedded Solutions LLC
 * @date       12.01.2024 (created)
 *
 **************************************************************************************************/

/***************************************************************************************************
 * INCLUDES
 **************************************************************************************************/
#include "System_Control_App.h"
#include "System_definitions.h"
#include "CmdMessenger.h"
#include "debugutils.h"
#include "CombinedControl.h"
#include <SPI.h>
#include "BLE_Bridge_App.h"

/***************************************************************************************************
 * CONSTANTS AND DEFINITIONS
 **************************************************************************************************/

/***************************************************************************************************
 * MODULE VARIABLES
 **************************************************************************************************/
CmdMessenger cmdMessenger = CmdMessenger(Serial); // Serial communication handler
String outputStr; // String buffer for serial output
CombinedControl control; // Object for managing motor and joystick control
flags motorFlags[3]; // Flags for motor status tracking
int status[25]; // Array for storing system status data
extern union floatUnion AveragedIMUdata[6];
extern uint32_t IMU_Comm_Errors;
BLE_Bridge_App BLE_App_sys;            /* Bluetooth application object */
uint8_t SysInitState = 0; /* Report initialization status of the system */

uint32_t motorStats[3]={0};

/***************************************************************************************************
 * PRIVATE FUNCTION PROTOTYPES
 **************************************************************************************************/
void attachCommandCallbacks(); /* Attach command handlers */
void _checkJS(uint8_t motorID); /* Check joystick input for a specific motor */
void OnUnknownCommand(); /* Handler for unknown serial commands */
void onRequestMotorStatus(); /* Request motor status */
void onRequestStallStatus(); /* Request stall status */
void onRequestSetPosNoMove(); /* Set motor position without movement */
void onSetSlowFastJSMotion(); /* Adjust joystick motion sensitivity */
void onSetJSMirrorMode(); /* Set joystick mirror mode */
void onGetXactual(); /* Get motor position */
void onGetVelocity(); /* Get motor velocity */
void onGetAcceleration(); /* Get motor acceleration */
void onGetDeceleration(); /* Get motor deceleration */
void onGetPower(); /* Get motor power consumption */
void onGetIMUData(); /* Collected averaged IMU data */

void onConstantForward(); /* Move motor at a constant speed forward */
void onConstantBackward(); /* Move motor at a constant speed backward */
void onMovePosition(); /* Move motor to a specified position */
void onMoveForward(); /* Move motor forward */
void onMoveBackward(); /* Move motor backward */
void onVelocity(); /* Set motor velocity */
void onAcceleration(); /* Set motor acceleration */
void onDeceleration(); /* Set motor deceleration */
void onPower(); /* Set motor power */
void onDirection(); /* Set motor direction */
void onJStoggleCntl(); /* Toggle joystick motorl control */
void onJSEnable(); /* Enable/Disable joystick control */
void onJSDisable(); /* Disable joystick control */
void onMotorStop(); /* Stop the motor */
void onMotorHome(); /* Move motor to home position */
void onSeek(); /* Seek operation for motor */
void onResolution(); /* Set resolution settings */
void onActiveSettings(); /* Get active settings */
void onPing(); /* Ping command handler */
double imu_heading_to_unsigned_360(double imu_heading);
double unsigned_360_to_signed_imu(double heading_360);

/***************************************************************************************************
 * FUNCTION DEFINITIONS
 **************************************************************************************************/

/***********************************************************************************************//**
 * @details     Initialize joystick and motor control pins, SPI, and motor controller.
 **************************************************************************************************/
void System_Control_App :: Init(void)
{
    /* =============== Setup Motor Control =============== */

    /* Configure enable and Chip Select pins for all motors */
    pinMode(MTR_CS0, OUTPUT);
    pinMode(MTR_CS1, OUTPUT);
    pinMode(MTR_CS2, OUTPUT);
    pinMode(MTR_ENA_0, OUTPUT);
    pinMode(MTR_ENA_1, OUTPUT);
    pinMode(MTR_ENA_2, OUTPUT);
    
    /* enable all, but motor 3 on startup */
    digitalWrite(MTR_ENA_0, LOW);
    digitalWrite(MTR_ENA_1, LOW);
    digitalWrite(MTR_ENA_2, HIGH);
    
    /* Configure joystick stop switch */
	PIOB->PIO_PER=(1<<27); //Enable PIO for GPIO P13
	PIOB->PIO_OER=(1<<27); //Enable port pin for output P13
    pinMode(JS_STOP_SWTICH, INPUT_PULLUP);

	Serial.begin(115200); /* Initialize serial communication */
    Serial.println("starting the coolest project in the history of mankind");
	
    /* Initialize SPI interface with appropriate settings */
    SPI.setBitOrder(MSBFIRST);
    SPI.setClockDivider(SPI_CLOCK_DIV8);
    SPI.setDataMode(SPI_MODE3);
    SPI.begin();

    /* =============== Initialize Objects =============== */

    /* Initialize motor and sensor control objects*/ 
    control.begin();

    /* Reserve memory for output string */ 
    outputStr.reserve(128);
    
    /* Ensure proper line endings for serial communication */ 
    cmdMessenger.printLfCr();
    
    /* Attach command callbacks for serial communication */ 
    attachCommandCallbacks();    
}
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

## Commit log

2024-06-03 Added System Drawings/WiringForControllers.drawio
2024-06-23 docs clean up. added new doc. minor updates
    [RotatingTableOneRevolution.xlsx]
2024-06-23 REverting ADC resolution back to 10 bits
    [System_definitions.h]
2024-06-23 My Changes (First parameter for motor)
2024-06-23 Completed motor extension for the first layer. Next layer below needs to be done next
2024-07-02 Parametrized motor
    [RotatingTableOneRevolution.xlsx]
2024-07-03 Added angular displacement limits for both motors
2024-07-09 Fixed Motor 0 range problem. Slowed down joystick control avoid motor jerking
    [CombinedControl.cpp, Main.cpp, MotorControl.cpp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]
2024-08-04 Added Python control program that uses Astropy to track planets
2025-01-05 Added I2C connection of IMU Updated GotoAstropyOffliney.py with new scan function
2025-01-31 Updated software architecture diagram and broke code down into modules to reflect the updates
    [Main.cpp, System_Control_App.cpp, Testy.py]
2025-02-02 Added init state machine Updated diagram to include new stepper motor 3 Updated code to include motor 3
2025-02-22 Updated drawings and Motor controls pins
2025-02-22 Created asynchronous LED blink for state -- needs implementation into main
2025-03-14 Added proper comments to application layer Separated code into folders Added LED_App
2025-05-10 Added joystick mode control. Pin 13 input still not working some IMU updates related to IMU angular measurements conversation to standard polar coordinates Updated documentation showing newly added p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
    [CombinedControl.cpp, GotoAstropyOffliney.py, Main.cpp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]
2025-06-14 Minor updates for commenting out the IMU. IMU consistent data collection is simply not reliable.
2025-06-14 Tweaked control script Added ToggleJSmtrlControlMode through uart interface
2025-06-17 Fix backspace bug to allow exit from scan menu
    [GotoAstropyOffliney.py]
2025-08-18 Broke Python script into modulized format Commented out BLE for testing
    [CombinedControl.cpp, GotoAstropyOffliney.py, IMU_control.py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]
2025-10-24 Switched to Seeeed_nRF52_BLE_UART instead of Adafruit. Replaced BNO080 with HWt906 IMU
    [BLE_Bridge_App.cpp, Main.cpp, Seeeed_nRF52_BLE_UART_Bridge_Sketch.ino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]
2026-05-06 so many fixes. I can't remember them all
    [BLE_Bridge_App.cpp, CombinedControl.cpp, LED_App.cpp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]
2026-05-12 PCB design files for TMC5130A Driver Board Shield - arduino compatible
    First iteration of driver board
    [TMC5130A Driver Board Shield For Arduino.PrjPcb, motor0_control.SchDoc, motor1_control.SchDoc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]
2026-05-12 Create Triple Stepper Motor Controller With Integrated TMC5130A-TA Drivers
